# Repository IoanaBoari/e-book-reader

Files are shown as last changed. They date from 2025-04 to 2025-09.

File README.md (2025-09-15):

### OpenBook - Project

## Block Diagram
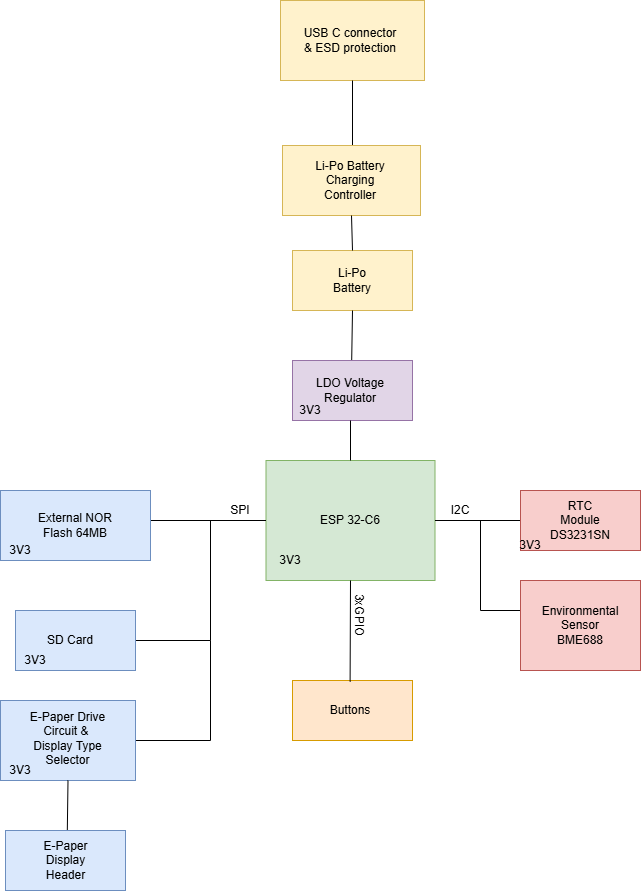
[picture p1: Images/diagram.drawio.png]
Block Diagram

---
## Bill Of Materials (BOM)
| Component | Source | Datasheet |
|---|---|---|
| Button | [Mouser](https://ro.mouser.com/ProductDetail/CK/KMR221GULCLFS?qs=u2NJ%252B70r0goBXaNk7IrU0Q%3D%3D) |[Datasheet](https://www.ckswitches.com/media/1479/kmr2.pdf)|
| Capacitor SUPERCAP | [Mouser](https://ro.mouser.com/ProductDetail/Seiko-Semiconductors/CPH3225A?qs=3etwrb1wR%252BhUOph6lAO7eg%3D%3D) | [Datasheet](https://ro.mouser.com/datasheet/2/360/Seiko_Instruments_MicroBattery_E_20230330_2024Jan_-3561061.pdf)|
| Capacitor 100nF | [Mouser](https://ro.mouser.com/ProductDetail/KEMET/C0402C104K4RAL?qs=pIZUS6sqCWCaMuP2QVR%2Fog%3D%3D) | [Datasheet](https://ro.mouser.com/datasheet/2/447/KEM_C1018_X7R_SnPb_SMD-3316276.pdf)|
| Capacitor 4.7uF | [Mouser](https://ro.mouser.com/ProductDetail/KEMET/C0402C475M9PAC7411?qs=cpo3%2FpBou2jRzZxyxJnMGg%3D%3D) | [Datasheet](https://ro.mouser.com/datasheet/2/447/KEM_C1006_X5R_SMD-3316465.pdf)|
| Capacitor 100uF TANT | [Mouser](https://ro.mouser.com/ProductDetail/KYOCERA-AVX/TAJW107M010RNJ?qs=Wtp%252Bf%2FAeVqIH8v1VxV%252B1Rg%3D%3D) | [Datasheet](https://ro.mouser.com/datasheet/2/40/TAJ-3165264.pdf)|
| Capacitor 4.7uF / 25V | [Mouser](https://ro.mouser.com/ProductDetail/KYOCERA-AVX/12063C475KAZ2A?qs=%252BdQmOuGyFcG3LdbVp5waMw%3D%3D) | [Datasheet](https://ro.mouser.com/datasheet/2/40/X7RDielectric-2943470.pdf)|
| Capacitor 1uF | [Mouser](https://ro.mouser.com/ProductDetail/KEMET/C0402C105K9PACTU?qs=UdQET6xYxVCMExqTDkuPeQ%3D%3D) | [Datasheet](https://ro.mouser.com/datasheet/2/447/KEM_C1006_X5R_SMD-3316465.pdf)|
| Capacitor 10uF | [Mouser](https://ro.mouser.com/ProductDetail/KEMET/C0402C106M9PACTU?qs=x4XeXhDQKnp%252Bz0lMlwMC3A%3D%3D) | [Datasheet](https://ro.mouser.com/datasheet/2/447/KEM_C1006_X5R_SMD-3316465.pdf)|
| CHG_LED | [CPC](https://cpc.farnell.com/kingbright/kpg-1608zgc/led-smd-0603-grn/dp/SC20796) | [Datasheet](https://www.farnell.com/datasheets/2046349.pdf)|
| USBLC6-2SC6Y | [Mouser](https://ro.mouser.com/ProductDetail/STMicroelectronics/USBLC6-2SC6Y?qs=gNDSiZmRJS%2FOgDexvXkdow%3D%3D) | [Datasheet](https://ro.mouser.com/datasheet/2/389/usblc6_2sc6y-1852505.pdf)|
| PGB1010603MR | [Mouser](https://ro.mouser.com/ProductDetail/Littelfuse/PGB1010603MR?qs=gu7KAQ731URLg4GSnNNN7Q%3D%3D) | [Datasheet](https://www.littelfuse.com/assetdocs/pulseguard-esd-suppressors-pgb1-datasheet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)|
| SD0805S020S1R0 | [Mouser](https://ro.mouser.com/ProductDetail/KYOCERA-AVX/SD0805S020S1R0?qs=jCA%252BPfw4LHbpkAoSnwrdjw%3D%3D) | [Datasheet](https://ro.mouser.com/datasheet/2/40/schottky-3165252.pdf)|
| MBR0530 | [Mouser](https://ro.mouser.com/ProductDetail/onsemi/MBR0530T3G?qs=3JMERSakebpEmdUS6GetdQ%3D%3D) | [Datasheet](https://www.onsemi.com/products/discrete-power-modules/schottky-diodes-schottky-rectifiers/mbr0530t3g)|
| Solder Jumper | [Grabcad](https://grabcad.com/library/solder-jumpers-1) | [Datasheet](https://grabcad.com/library/solder-jumpers-1)|
| Capacitor 1uF / 50V | [Mouser](https://ro.mouser.com/ProductDetail/TDK/C1608X7R1H105K080AB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) | [Datasheet](https://product.tdk.com/system/files/dam/doc/product/capacitor/ceramic/mlcc/catalog/mlcc_commercial_general_en.pdf)|
| Capacitor 0.1uF / 50V | [Farnell](https://ro.farnell.com/multicomp-pro/mcmlr50v104kx7r/ceramic-capacitor-0-1uf-50v-x7r/dp/1600875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) | [Datasheet](https://www.farnell.com/datasheets/2873577.pdf?_gl=1*x28a2*_gcl_au*MTYwODAzNzc2OC4xNzQzNDM1MjM4)|
| BD5229G-TR | [Mouser](https://ro.mouser.com/ProductDetail/ROHM-Semiconductor/BD5229G-TR?qs=4kLU8WoGk0vvnhrrYwdszw%3D%3D) | [Datasheet](https://fscdn.rohm.com/en/products/databook/datasheet/ic/power/voltage_detector/bd52xxg-e.pdf)|
| XC6220A331MR-G | [Mouser](https://ro.mouser.com/ProductDetail/Torex-Semiconductor/XC6220A331MR-G?qs=AsjdqWjXhJ8ZSWznL1J0gg%3D%3D) | [Datasheet](https://ro.mouser.com/datasheet/2/760/xc6220-3371556.pdf)|
| FH34SRJ-24S-0.5SH_99_ | [Mouser](https://ro.mouser.com/ProductDetail/Hirose-Connector/FH34SRJ-24S-0.5SH99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) | [Datasheet](https://ro.mouser.com/datasheet/2/185/FH34SRJ_24S_0_5SH_99__CL0580_1255_6_99_2DDrawing_0-1615044.pdf)|
| SAMACSYS_PARTS_USB4110-GF-A | [Mouser](https://ro.mouser.com/ProductDetail/GCT/USB4110-GF-A?qs=KUoIvG%2F9IlYiZvIXQjyJeA%3D%3D) | [Datasheet](https://ro.mouser.com/datasheet/2/837/GCT_USB4110_Product_Drawing___20k_cycles-3455479.pdf)|
| QWIIC_RIGHT_ANGLEA | [Mouser](https://ro.mouser.com/ProductDetail/JST-Commercial/SM04B-SRSS-TBLFSN?qs=cdbOS8ANM9B3FdyA6cNU2A%3D%3D) | [Datasheet](https://ro.mouser.com/datasheet/2/564/eSR_SZ-3476820.pdf)|
| 112A-TAAR-R03_ATTEND | [LCSC](https://www.lcsc.com/product-detail/SD-Card-Connectors_Attend-Technology-112A-TAAR-R03_C6970445.html) | [Datasheet](https://www.lcsc.com/datasheet/lcsc_datasheet_2411220717_Attend-Technology-112A-TAAR-R03_C6970445.pdf)|
| Bobina | [Mouser](https://ro.mouser.com/ProductDetail/Wurth-Elektronik/744043680?qs=PGXP4M47uW6VkZq%252BkzjrHA%3D%3D) | [Datasheet](https://www.we-online.com/components/products/datasheet/744043680.pdf)|
| MCP73831 | [Mouser](https://ro.mouser.com/ProductDetail/Microchip-Technology/MCP73831-2ACI-MC?qs=hH%252BOa0VZEiBneYTVdpuVdg%3D%3D) | [Datasheet](https://ro.mouser.com/datasheet/2/268/MCP73831_Family_Data_Sheet_DS20001984H-3441711.pdf)|
| PFMF.050.1 | [Mouser](https://ro.mouser.com/ProductDetail/Schurter/PFMF.050.2?qs=1auRipcfynCums5v1iucSA%3D%3D) | [Datasheet](https://ro.mouser.com/datasheet/2/358/typ_PFMF-1275918.pdf)|
| DMG2305UX-7 | [Mouser](https://ro.mouser.com/ProductDetail/Diodes-Incorporated/DMG2305UX-7?qs=L1DZKBg7t5F%2FNBHrjfxC%252Bg%3D%3D) | [Datasheet](https://www.diodes.com/assets/Datasheets/DMG2305UX.pdf)|
| SI1308EDL-T1-GE3 | [Mouser](https://ro.mouser.com/ProductDetail/Vishay-Semiconductors/SI1308EDL-T1-GE3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) | [Datasheet](https://www.vishay.com/docs/63399/si1308edl.pdf)|
| Resistor 10K | [DigiKey](https://www.digikey.com/en/products/detail/venkel/CR0402-10W-102JT/12332774) | [Datasheet](https://data.venkel.com/documents/cr-series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.)|
| Resistor 100K | [Venkel](https://venkel.com/part/CR0402-16W-1003FT) | [Datasheet](https://data.venkel.com/documents/cr-series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.)|
| Resistor 5k1 | [Venkel](https://venkel.com/part/CR0402-10W-5101FT) | [Datasheet](https://data.venkel.com/documents/cr-series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.)|
| Resistor 2k | [Venkel](https://www.venkel.com/part/CR0402-16W-2002FT) | [Datasheet](https://data.venkel.com/documents/cr-series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.)|
| Resistor 0.47 | [Mouser](https://ro.mouser.com/ProductDetail/Vishay-Beyschlag/MCT06030C4700FP500?qs=XsZ9OvPb0dt82KlzjdcMjQ%3D%3D) | [Datasheet](https://www.vishay.com/docs/28705/mcx0x0xpro.pdf)|
| BME688 | [Mouser](https://ro.mouser.com/ProductDetail/Bosch-Sensortec/BME688?qs=IS%252B4QmGtzzqQoVDscqwx3A%3D%3D) | [Datasheet](https://ro.mouser.com/datasheet/2/783/bst_bme688_fl000-2307034.pdf)|
| W25Q512JVEIQ | [Mouser](https://ro.mouser.com/ProductDetail/Winbond/W25Q512JVEIQ?qs=l7cgNqFNU1jw6svr3at6tA%3D%3D) | [Datasheet](https://ro.mouser.com/datasheet/2/949/Winbond_W25Q512JV_Datasheet-3240039.pdf)|
| ESP32-C6-WROOM-1-N8 | [Mouser](https://ro.mouser.com/ProductDetail/Espressif-Systems/ESP32-C6-WROOM-1-N8?qs=8Wlm6%252BaMh8ST02Gmwp74cw%3D%3D) | [Datasheet](https://ro.mouser.com/datasheet/2/891/Espressif_ESP32_C6_WROOM_1__Datasheet_V0_1_PRELIMI-3239987.pdf)|
| DS3231SN# | [Mouser](https://ro.mouser.com/ProductDetail/Analog-Devices-Maxim-Integrated/DS3231SN?qs=1eQvB6Dk1vhUlr8%2FOrV0Fw%3D%3D) | [Datasheet](https://ro.mouser.com/datasheet/2/609/DS3231-3421123.pdf)|
| MAX17048G+T10 | [Mouser](https://ro.mouser.com/ProductDetail/Analog-Devices-Maxim-Integrated/MAX17048G%2bT10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) | [Datasheet](https://ro.mouser.com/datasheet/2/609/MAX17048_MAX17049-3469099.pdf)|
| Test Pad | [DigiKey](https://www.digikey.com/en/products/detail/keystone-electronics/5006/255330) | [Datasheet](https://www.keyelco.com/userAssets/file/M65p56.pdf)|

---

# Hardware Functionality

**Power Supply & Energy Management:**
- **USB with ESD:** Provides power and protects data lines.
- **Li-Po Charging Circuit - MCP73831:** Controlled charging for the 1800 mAh battery.
- **Li-Po Battery & LDO Voltage Regulator:** Regulates voltage to 3.3V for all modules.

**Microcontroller & Interfaces:**
- **ESP32-C6:**
    - **SPI:** Connects NOR Flash memory, SD card, and e-paper display.
    - **I2C:** Connects RTC DS3231, BME688 sensor, and expansion modules.
    - **UART:** For debugging and serial communication.
    - **GPIO:** For buttons and test pads.

**Storage & Display Modules:**
- **NOR Flash Memory (SPI)** Fast storage for firmware and data.
- **SD Card (SPI)** Expands storage capacity.
- **E-Paper Display:** Low-power, precise updates, controlled via SPI.

**Additional Modules & Sensors:**
- **RTC DS3231 (I2C):** Real-time clock.
- **BME688 Sensor (I2C):** Measures temperature, humidity, pressure, and air quality.
- **Qwiic/Stemma QT Connector (I2C):** Allows expansion with additional modules.
- **Test Pads & Buttons (GPIO):** Facilitate direct control and diagnostics.

**Power Optimization:**
- **ESP32-C6 Low-Power Mode:** Reduces consumption through dynamic frequency and activity management.
- **Stable LDO:** Ensures a constant 3.3V voltage.
- **SMD Components (e.g., 0402 capacitors):** Minimize consumption through small size and improved efficiency.

---

# ESP32-C6 Pin Mapping

| Nume | GPIO | Usage | Notes |
|---|---|---|---|
| 3V3  | 3V3 | 3.3V Power Supply | Voltage source for ESP32-C6 and logic components. |
| SCK (SPI) | IO6 | SPI Clock | Provides the clock signal for high-speed data transfers. |
| MOSI (SPI) | IO7 | SPI Data Transmission | Sends data to NOR Flash, SD Card, and E-Paper. |
| MISO (SPI) | IO2 | SPI Data Reception | Receives data from SPI devices. |
| FLASH_CS | IO11 | SPI Chip Select for NOR Flash | Selects the NOR Flash memory on the SPI bus. |
| EPD_CS | IO10 | SPI Chip Select for E-Paper | Selects the e-paper display. |
| SDA (I2C) | IO21 | I2C Data Line | Connects RTC DS3231, BME688 sensor, and Qwiic/Stemma QT connector. |
| SCL (I2C) | IO22 | I2C Clock Line | Synchronizes I2C communication. |
| TX (UART) | TXD0/GPIO16 | UART Data Transmission | Used for debugging and serial communication. |
| RX (UART) | RXD0/GPIO17 | UART Data Reception | Used for debugging and serial communication. |
| Buton Reset | EN | ESP32-C6 Reset | Pin dedicat pentru resetul sistemului. |
| Buton Boot | IO9 | Bootloader Entry | Dedicated pin to enter boot mode. |
| Buton Change | IO15 | Operation Mode Switch | Allows switching between different operating modes. |
| EPD DC | IO5 | Data/Command for E-Paper | Distinguishes between command and data signals for the display. |
| EPD RST | IO23 | E-Paper Reset | Resets the e-paper display when needed. |
| EPD BUSY | IO3 | E-Paper Busy Indicator | Signal indicating if the display is currently busy. |
| INT_RTC | IO0 | RTC Interrupt Signal (DS3231) | Triggers the microcontroller. |
| 32KHZ | IO1 | 32 kHz Clock Signal | Oscillation line for DS3231 or other modules (not directly connected to ESP). |
| SS_SD| IO4 | SPI Chip Select for SD Card | Selects the SD card on the SPI bus. |
| USB_D- | IO12 | USB Differential Line (minus) | Connection to the USB port. |
| USB_D+ | IO13 | USB Differential Line (plus) | Connection to the USB port. |
| RTC_RST | IO18 | External RTC Reset/Signal | Used to reset the real-time clock. |
| I2C_PW | IO19 | I2C Power/Enable Line | Turns I2C sensors on/off to save energy. |
| EPD_3V3_C | IO20 | 3.3V Power Line for E-Paper | Provides 3.3V specifically for the e-paper display, separate from main power, to ensure signal stability. |

---
## Motivation

- **SPI** (SCK, MOSI, MISO, CS lines) provides fast transfer for external memory (Flash), SD card, and e-paper display.
- **I2C** (SDA, SCL) connects sensors (RTC, BME688) and the Qwiic connector, allowing bus sharing with low power consumption.
- **UART** (TX, RX) is used for debugging.
- **Additional GPIOs** (buttons, test pads) facilitate manual control and diagnostics.

---

## Implementation Steps

- **Schematic:** Created the schematic according to the project requirements.
- **PCB Redesign:** Redesigned the PCB and placed components on the board based on the reference model.
- **Autorouting:** Performed autorouting on both top and bottom layers, using a 0.15 mm trace width for signal lines.
- **Power Net Class:** Grouped power traces into a net class, highlighted them, and manually adjusted to 0.3 mm to ensure robust power delivery.
- **Ground Planes and Via Stitching:** Added ground planes on top and bottom layers and applied via stitching near the ESP module for optimal inter-layer connectivity.
- **3D Models:** Downloaded component 3D models from [ComponentSearchEngine](https://componentsearchengine.com/), imported them into Fusion 360, and placed them on the PCB.
- **Enclosure Integration:** Inserted the PCB into the enclosure and modified it to properly fit the buttons and connectors.
- **3D Models for Battery and Display:** Created 3D models for the battery and display, connecting wires to the corresponding test pads and ensuring correct placement inside the enclosure.
- **Export:** Finally, generated Gerber files, Pick and Place (CPL), and BOM, preparing them for upload and production.

---

## Issues Encountered and Error Acceptance Decisions

- **3D Model for Button:**  
  Could not find a 3D model for the button that perfectly matched the project requirements, so I modified an existing model to fit the design.

- **SMD-Hole Board Outline Clearance Errors at USB Connector:**  
  Encountered two SMD-Hole Board Outline Clearance errors at the USB connector. These errors were accepted according to the provided guidelines.
---

## Conclusion
 I resolved the reported issues by adjusting the PCB thickness and adding 3D models for the solder jumper and test pads.
 For the test pads, I implemented a custom model.

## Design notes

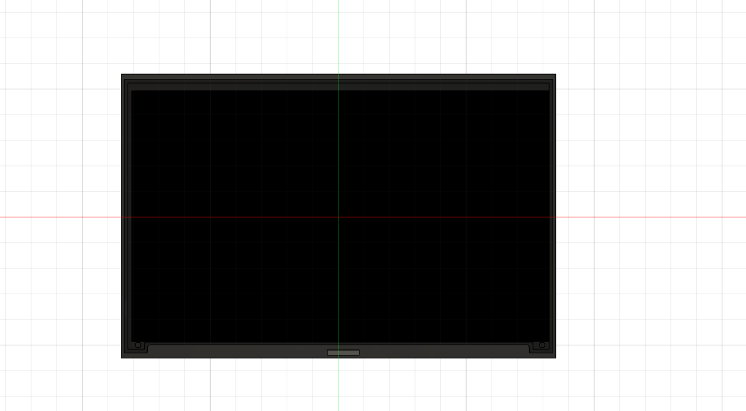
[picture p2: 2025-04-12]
Images/Display1.png

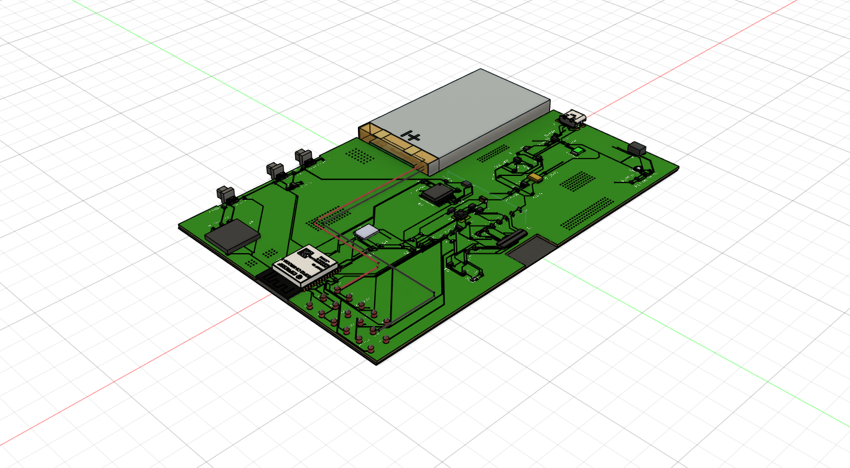
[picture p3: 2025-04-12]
Images/Dispozitiv6.png

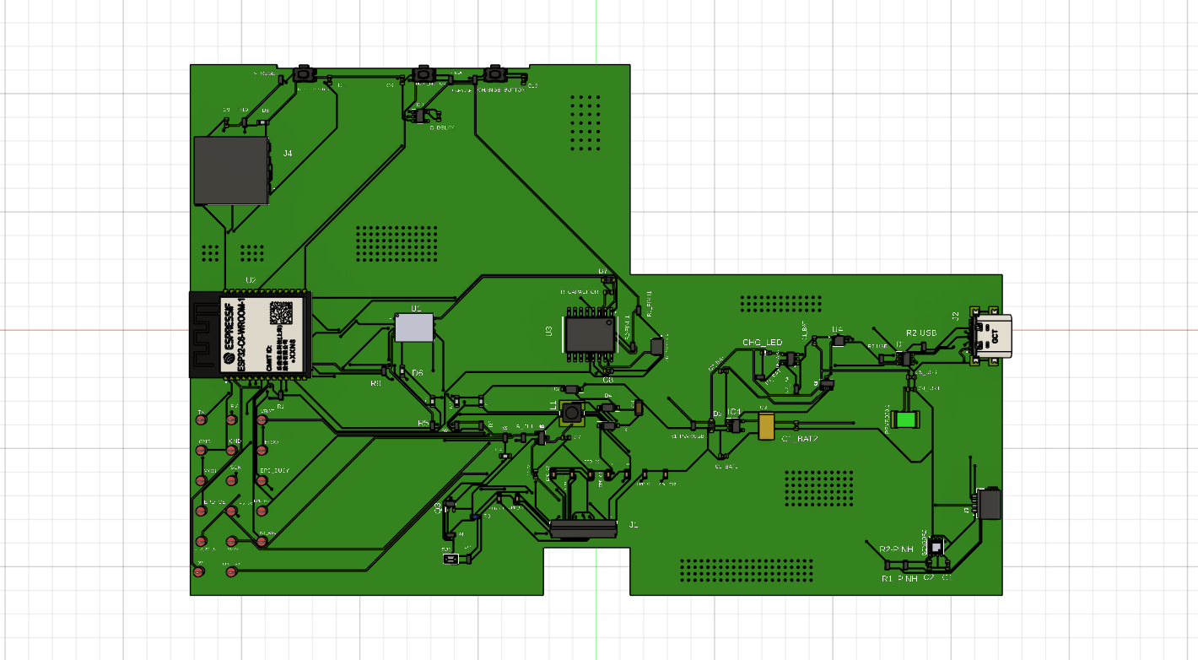
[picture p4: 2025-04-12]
Images/Board1.png

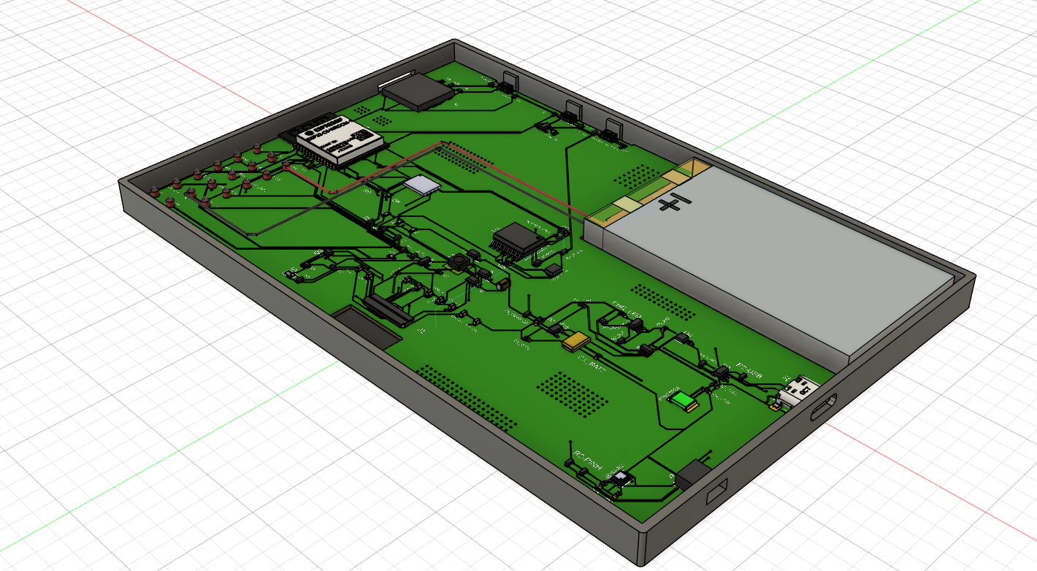
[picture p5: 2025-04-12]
Images/Dispozitiv3.png

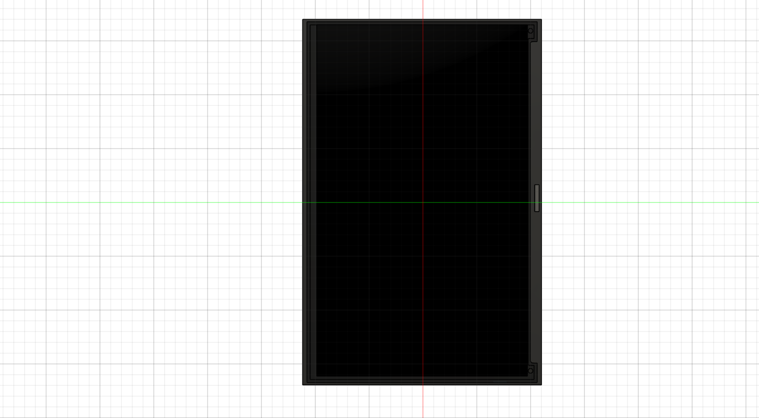
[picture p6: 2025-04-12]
Images/Display2.png

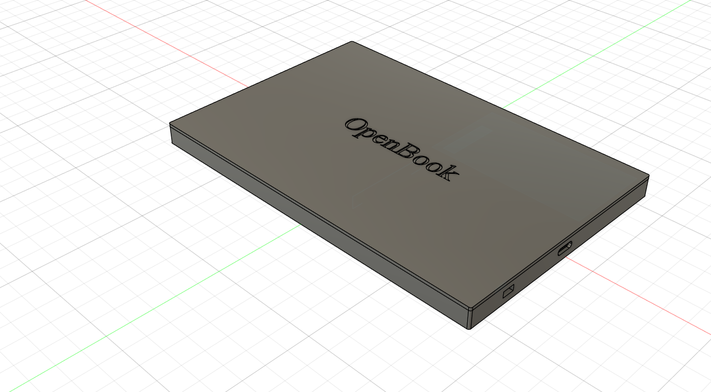
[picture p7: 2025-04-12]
Images/Dispozitiv1.png

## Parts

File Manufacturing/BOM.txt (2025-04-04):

BOOT_BUTTON	49.00	108.91	180.00	BUTTON_CUSYOMV1	MYBUTTON
C1	158.75	6.35	90.00	100nF	ESP32_WROVER_EAGLE-LTSPICE_C0402
C10	69.85	107.95	90.00	100nF	ESP32_WROVER_EAGLE-LTSPICE_C0402
C10_SUPERCAP	97.79	52.07	270.00	CPH3225A	CAPCP3225X100N
C1_BAT	130.81	53.34	90.00	4.7uF	ESP32_WROVER_EAGLE-LTSPICE_C0402
C1_BAT1	111.76	29.21	0.00	4.7uF	ESP32_WROVER_EAGLE-LTSPICE_C0402
C1_BAT2	127.00	35.56	270.00	4.7uF	EAGLE-LTSPICE_C0402
C2	154.94	6.35	90.00	100nF	ESP32_WROVER_EAGLE-LTSPICE_C0402
C2_BAT	111.76	46.99	0.00	4.7uF	ESP32_WROVER_EAGLE-LTSPICE_C0402
C3	120.65	35.56	270.00	100uF TANT	RCL_CT3528
C4	93.98	39.37	90.00	4.7uF/25V	ESP32_WROVER_EAGLE-LTSPICE_C0402
C4_USB	151.13	43.18	0.00	100nF	ESP32_WROVER_EAGLE-LTSPICE_C0402
C5	29.21	107.95	90.00	1uF	ESP32_WROVER_EAGLE-LTSPICE_C0402
C5_USB	151.13	45.72	0.00	4.7uF	ESP32_WROVER_EAGLE-LTSPICE_C0402
C6	44.45	107.95	90.00	100nF	ESP32_WROVER_EAGLE-LTSPICE_C0402
C7	78.74	33.02	0.00	10uF	ESP32_WROVER_EAGLE-LTSPICE_C0402
C8	87.63	46.99	0.00	100nF	ESP32_WROVER_EAGLE-LTSPICE_C0402
C9	7.62	99.06	90.00	100nF	ESP32_WROVER_EAGLE-LTSPICE_C0402
CHANGE_BUTTON	64.00	108.91	180.00	BUTTON_CUSYOMV1	MYBUTTON
CHG_LED	120.65	50.80	90.00		ADAFRUIT_CHIP-LED0603
C_DELAY	52.07	100.33	90.00	100nF	ESP32_WROVER_EAGLE-LTSPICE_C0402
D1	149.86	49.53	0.00	USBLC6-2SC6Y	SOT95P280X145-6N
D10	55.88	40.64	90.00	PGB1010603MR	DIOC1608X36N
D11	60.96	40.64	90.00	PGB1010603MR	DIOC1608X36N
D12	66.04	29.21	0.00	PGB1010603MR	DIOC1608X36N
D2	109.22	35.56	90.00	ESP32_WROVER_AVX---SD0805S020S1R0_AVX_SD0805S020S1R0_0_0AVX_SD0805S020S1R0_0_0	ESP32_WROVER_AVX---SD0805S020S1R0_AVX_SD0805S020S1R0_0
D3	80.01	43.18	180.00	MBR0530	SOD3716X135N
D4	87.63	39.37	180.00	MBR0530	SOD3716X135N
D5	87.63	35.56	0.00	MBR0530	SOD3716X135N
D6	44.45	46.99	90.00	PGB1010603MR	DIOC1608X36N
D7	87.63	66.04	0.00	ESP32_WROVER_AVX---SD0805S020S1R0_AVX_SD0805S020S1R0_0_0AVX_SD0805S020S1R0_0_0	ESP32_WROVER_AVX---SD0805S020S1R0_AVX_SD0805S020S1R0_0
D8	15.24	99.06	0.00	PGB1010603MR	DIOC1608X36N
D9	50.80	40.64	90.00	PGB1010603MR	DIOC1608X36N
EPD_C1	64.77	20.32	90.00	1uF/50V	ESP32_WROVER_EAGLE-LTSPICE_C0402
EPD_C10	91.44	25.40	90.00	1uF/50V	ESP32_WROVER_EAGLE-LTSPICE_C0402
EPD_C11	95.25	25.40	90.00	1uF/50V	ESP32_WROVER_EAGLE-LTSPICE_C0402
EPD_C12	99.58	25.40	90.00	1uF/50V	ESP32_WROVER_EAGLE-LTSPICE_C0402
EPD_C2	68.58	20.32	90.00	1uF/50V	ESP32_WROVER_EAGLE-LTSPICE_C0402
EPD_C5	72.39	25.40	90.00	0.1uF/50V	ESP32_WROVER_EAGLE-LTSPICE_C0402
EPD_C6	76.20	25.40	90.00	1uF/50V	ESP32_WROVER_EAGLE-LTSPICE_C0402
EPD_C7	80.01	25.40	90.00	1uF/50V	ESP32_WROVER_EAGLE-LTSPICE_C0402
EPD_C8	83.82	25.40	90.00	1uF/50V	ESP32_WROVER_EAGLE-LTSPICE_C0402
EPD_C9	87.63	25.40	90.00	1uF/50V	ESP32_WROVER_EAGLE-LTSPICE_C0402
IC1	48.26	100.33	0.00	BD5229G-TR	SOT95P280X125-5N
IC4	114.30	35.56	0.00	XC6220A331MR-G	SOT95P280X120-5N
J1	82.42	14.20	0.00	FH34SRJ-24S-0.5SH_99_	FH34SRJ24S05SH99
J2	166.09	54.30	90.00	SAMACSYS_PARTS_USB4110-GF-A	SAMACSYS_PARTS_USB4110GFA
J3	166.35	19.30	90.00	QWIIC_RIGHT_ANGLE	JST04_1MM_RA
J4	9.09	88.88	270.00	112A-TAAR-R03_ATTEND	112ATAARR03ATTEND
L1	80.01	38.10	270.00	68uH	IND_4828-WE-TPC_WRE
MCP73831	125.73	49.53	90.00	MCP73831	ESP32_WROVER_SPARKFUN-IC-POWER_SOT23-5
PFMF.050.1	149.86	36.83	0.00	ESP32C6_VARISTORCN1812	ESP32C6_VARISTOR_CT/CN1812
Q1	133.35	44.50	0.00	20V/4.2A/52mΩ/1.4W	ESP32_WROVER_SPARKFUN-DISCRETESEMI_SOT23-3
Q2	73.71	33.02	270.00	20V/4.2A/52mΩ/1.4W	ESP32_WROVER_SPARKFUN-DISCRETESEMI_SOT23-3
Q3	54.61	19.05	90.00	SI1308EDL-T1-GE3	SOT65P210X110-3N
R1	19.05	41.91	90.00	10K	ESP32_WROVER_EAGLE-LTSPICE_R0402
R10	11.43	99.06	90.00	10K	ESP32_WROVER_EAGLE-LTSPICE_R0402
R1_BAT	119.38	45.72	0.00	200	ESP32_WROVER_EAGLE-LTSPICE_R0402
R1_PINH	149.86	6.35	90.00	10K	ESP32_WROVER_EAGLE-LTSPICE_R0402
R1_PINH1	93.98	59.69	90.00	10K	ESP32_WROVER_EAGLE-LTSPICE_R0402
R1_PWRUSB	105.41	35.56	90.00	100K	ESP32_WROVER_EAGLE-LTSPICE_R0402
R2	58.42	7.62	90.00	2.2	ESP32_WROVER_EAGLE-LTSPICE_R0402
R2-PINH	146.05	6.35	90.00	10K	ESP32_WROVER_EAGLE-LTSPICE_R0402
R2-PINH1	92.71	52.07	90.00	10K	ESP32_WROVER_EAGLE-LTSPICE_R0402
R2-USB	153.67	52.07	90.00	5K1	ESP32_WROVER_EAGLE-LTSPICE_R0402
R2-USB1	144.78	49.53	90.00	5K1	ESP32_WROVER_EAGLE-LTSPICE_R0402
R2_BAT	127.00	43.18	90.00	2K	ESP32_WROVER_EAGLE-LTSPICE_R0402
R3	59.69	16.51	0.00	0.47	ESP32_WROVER_EAGLE-LTSPICE_R0402
R4	54.61	12.70	0.00	10K	ESP32_WROVER_EAGLE-LTSPICE_R0402
R5	50.80	35.56	90.00	10K	ESP32_WROVER_EAGLE-LTSPICE_R0402
R6	55.88	35.56	90.00	10K	ESP32_WROVER_EAGLE-LTSPICE_R0402
R7	60.96	35.56	90.00	10K	ESP32_WROVER_EAGLE-LTSPICE_R0402
R8	66.04	33.02	90.00	10K	ESP32_WROVER_EAGLE-LTSPICE_R0402
R9	40.64	46.99	90.00	10K	ESP32_WROVER_EAGLE-LTSPICE_R0402
RESET_BUTTON	24.00	108.91	180.00	BUTTON_CUSYOMV1	MYBUTTON
R_BOOT	54.61	107.95	90.00	10K	ESP32_WROVER_EAGLE-LTSPICE_R0402
R_CAPACITOR	87.63	63.50	180.00	15	ESP32_WROVER_EAGLE-LTSPICE_R0402
R_CHANGE	59.69	107.95	90.00	10K	ESP32_WROVER_EAGLE-LTSPICE_R0402
R_CL1	69.85	33.02	90.00	10K	ESP32_WROVER_EAGLE-LTSPICE_R0402
R_RESET	19.05	107.95	90.00	10K	ESP32_WROVER_EAGLE-LTSPICE_R0402
SENSOR2	156.22	10.16	90.00	BME688	ESP32_WROVER_BME680_PSON80P300X300X100-8N
SJ1	54.61	7.62	0.00		SJ
TP1	2.54	36.83	0.00	TPTP20R	TP20R
TP10	2.54	17.78	0.00	TPTP20R	TP20R
TP11	8.89	17.78	0.00	TPTP20R	TP20R
TP12	15.24	17.78	0.00	TPTP20R	TP20R
TP13	2.54	11.43	0.00	TPTP20R	TP20R
TP14	8.89	11.43	0.00	TPTP20R	TP20R
TP15	15.24	11.43	0.00	TPTP20R	TP20R
TP16	2.02	5.08	0.00	TPTP20R	TP20R
TP17	8.89	5.08	0.00	TPTP20R	TP20R
TP2	8.89	36.83	0.00	TPTP20R	TP20R
TP3	15.24	36.83	0.00	TPTP20R	TP20R
TP4	2.54	30.48	0.00	TPTP20R	TP20R
TP5	8.89	30.48	0.00	TPTP20R	TP20R
TP6	15.24	30.48	0.00	TPTP20R	TP20R
TP7	2.54	24.13	0.00	TPTP20R	TP20R
TP8	8.89	24.13	0.00	TPTP20R	TP20R
TP9	15.24	24.13	0.00	TPTP20R	TP20R
U1	46.99	56.09	0.00	W25Q512JVEIQ	SON127P600X800X80-9N
U2	15.70	54.61	90.00	ESP32-C6-WROOM-1-N8	XCVR_ESP32-C6-WROOM-1-N8
U3	83.82	54.61	270.00	DS3231SN#	SOIC127P1032X265-16N
U4	135.89	53.34	0.00	MAX17048G+T10	SON50P200X200X80-9N

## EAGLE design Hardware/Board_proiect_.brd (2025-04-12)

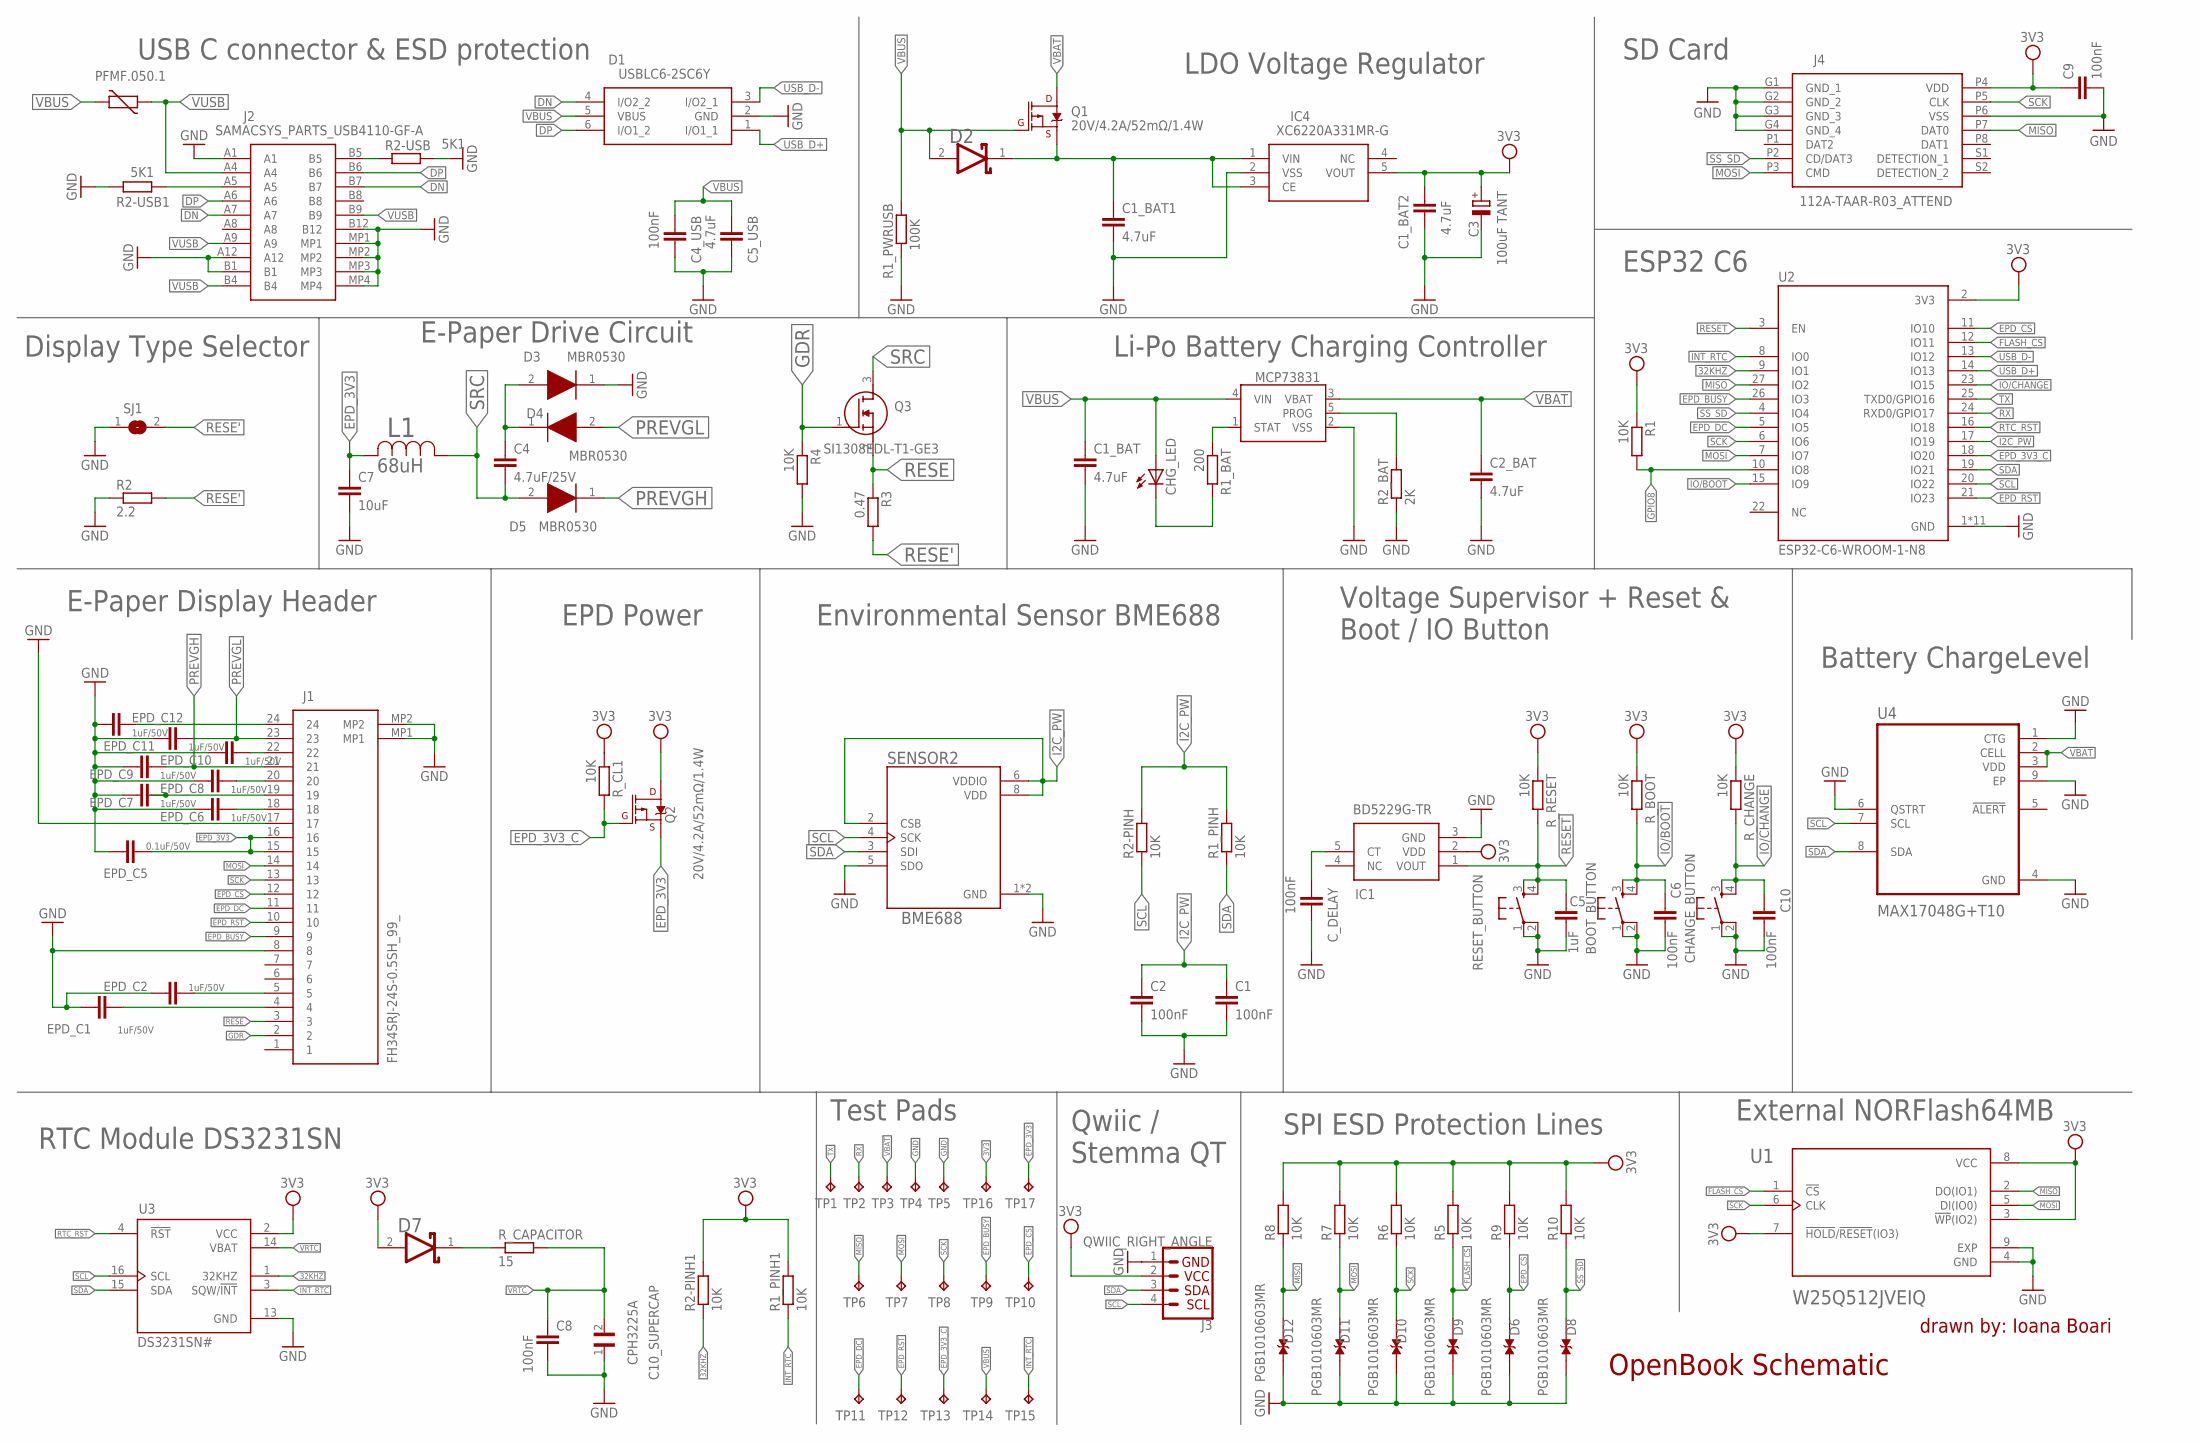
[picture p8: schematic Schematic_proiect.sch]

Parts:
BOOT_BUTTON: BUTTON_CUSYOMV1; MYBUTTON
C1, C2, C4_USB, C6, C8, C9, C10: 100nF; ESP32_WROVER_EAGLE-LTSPICE_C0402
C1_BAT, C1_BAT1, C2_BAT, C5_USB: 4.7uF; ESP32_WROVER_EAGLE-LTSPICE_C0402
C1_BAT2: 4.7uF; EAGLE-LTSPICE_C0402
C3: 100uF TANT; RCL_CT3528
C4: 4.7uF/25V; ESP32_WROVER_EAGLE-LTSPICE_C0402
C5: 1uF; ESP32_WROVER_EAGLE-LTSPICE_C0402
C7: 10uF; ESP32_WROVER_EAGLE-LTSPICE_C0402
C10_SUPERCAP: CPH3225A; CAPCP3225X100N
CHANGE_BUTTON: BUTTON_CUSYOMV1; MYBUTTON
CHG_LED: ADAFRUIT_LEDCHIP-LED0603; ADAFRUIT_CHIP-LED0603
C_DELAY: 100nF; ESP32_WROVER_EAGLE-LTSPICE_C0402
D1: USBLC6-2SC6Y; SOT95P280X145-6N
D2, D7: ESP32_WROVER_AVX---SD0805S020S1R0_AVX_SD0805S020S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; ESP32_WROVER_AVX---SD0805S020S1R0_AVX_SD0805S020S1R0_0
D3, D4, D5: MBR0530; SOD3716X135N
D6, D8, D9, D10, D11, D12: PGB1010603MR; DIOC1608X36N
EPD_C1, EPD_C2, EPD_C6, EPD_C7, EPD_C8, EPD_C9, EPD_C10, EPD_C11, EPD_C12: 1uF/50V; ESP32_WROVER_EAGLE-LTSPICE_C0402
EPD_C5: 0.1uF/50V; ESP32_WROVER_EAGLE-LTSPICE_C0402
IC1: BD5229G-TR; SOT95P280X125-5N
IC4: XC6220A331MR-G; SOT95P280X120-5N
J1: FH34SRJ-24S-0.5SH_99_; FH34SRJ24S05SH99
J2: SAMACSYS_PARTS_USB4110-GF-A; SAMACSYS_PARTS_USB4110GFA
J3: QWIIC_RIGHT_ANGLE; JST04_1MM_RA
J4: 112A-TAAR-R03_ATTEND; 112ATAARR03ATTEND
L1: 68uH; IND_4828-WE-TPC_WRE
MCP73831: MCP73831; ESP32_WROVER_SPARKFUN-IC-POWER_SOT23-5
PFMF.050.1: ESP32C6_VARISTORCN1812; ESP32C6_VARISTOR_CT/CN1812
Q1, Q2: 20V/4.2A/52mΩ/1.4W; ESP32_WROVER_SPARKFUN-DISCRETESEMI_SOT23-3
Q3: SI1308EDL-T1-GE3; SOT65P210X110-3N
R1, R1_PINH, R1_PINH1, R2-PINH, R2-PINH1, R4, R5, R6, R7, R8, R9, R10: 10K; ESP32_WROVER_EAGLE-LTSPICE_R0402
R1_BAT: 200; ESP32_WROVER_EAGLE-LTSPICE_R0402
R1_PWRUSB: 100K; ESP32_WROVER_EAGLE-LTSPICE_R0402
R2: 2.2; ESP32_WROVER_EAGLE-LTSPICE_R0402
R2-USB, R2-USB1: 5K1; ESP32_WROVER_EAGLE-LTSPICE_R0402
R2_BAT: 2K; ESP32_WROVER_EAGLE-LTSPICE_R0402
R3: 0.47; ESP32_WROVER_EAGLE-LTSPICE_R0402
RESET_BUTTON: BUTTON_CUSYOMV1; MYBUTTON
R_BOOT: 10K; ESP32_WROVER_EAGLE-LTSPICE_R0402
R_CAPACITOR: 15; ESP32_WROVER_EAGLE-LTSPICE_R0402
R_CHANGE: 10K; ESP32_WROVER_EAGLE-LTSPICE_R0402
R_CL1: 10K; ESP32_WROVER_EAGLE-LTSPICE_R0402
R_RESET: 10K; ESP32_WROVER_EAGLE-LTSPICE_R0402
SENSOR2: BME688; ESP32_WROVER_BME680_PSON80P300X300X100-8N
SJ1: SJ
TP1, TP2, TP3, TP4, TP5, TP6, TP7, TP8, TP9, TP10, TP11, TP12, TP13, TP14, TP15, TP16, TP17: TPTP20R; TP20R
U1: W25Q512JVEIQ; SON127P600X800X80-9N
U2: ESP32-C6-WROOM-1-N8; XCVR_ESP32-C6-WROOM-1-N8
U3: DS3231SN#; SOIC127P1032X265-16N
U4: MAX17048G+T10; SON50P200X200X80-9N

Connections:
3V3: C1_BAT2.1, C3.+, C9.1, D7.2 (ANODE), IC1.2 (VDD), IC4.5 (VOUT), J3.2, J4.P4 (VDD), Q2.3 (D), R1.1, R1_PINH1.2, R2-PINH1.2, R5.2, R6.2, R7.2, R8.2, R9.2, R10.2, R_BOOT.1, R_CHANGE.1, R_CL1.1, R_RESET.1, TP16.TP, U1.3 (!WP!(IO2)), U1.7 (!HOLD!/!RESET!(IO3)), U1.8 (VCC), U2.2 (3V3), U3.2 (VCC)
32KHZ: R2-PINH1.1, U2.9 (IO1), U3.1 (32KHZ)
DN: D1.4 (I/O2_2), J2.A7, J2.B7
DP: D1.6 (I/O1_2), J2.A6, J2.B6
EPD_3V3: C7.1, EPD_C5.1, J1.15, J1.16, L1.2, Q2.2 (S), TP17.TP
EPD_3V3_C: Q2.1 (G), R_CL1.2, TP13.TP, U2.18 (IO20)
EPD_BUSY: J1.9, TP9.TP, U2.26 (IO3)
EPD_CS: D6.1, J1.12, R9.1, TP10.TP, U2.11 (IO10)
EPD_DC: J1.11, TP11.TP, U2.5 (IO5)
EPD_RST: J1.10, TP12.TP, U2.21 (IO23)
FLASH_CS: D9.1, R5.1, U1.1 (!CS), U2.12 (IO11)
GDR: J1.2, Q3.1 (G), R4.1
GND: BOOT_BUTTON.1, BOOT_BUTTON.2, C1.2, C1_BAT.2, C1_BAT1.2, C1_BAT2.2, C2.2, C2_BAT.2, C3.-, C4_USB.2, C5.2, C5_USB.2, C6.2, C7.2, C8.2, C9.2, C10.2, C10_SUPERCAP.1, CHANGE_BUTTON.1, CHANGE_BUTTON.2, C_DELAY.2, D1.2 (GND), D3.1 (K), D6.2, D8.2, D9.2, D10.2, D11.2, D12.2, EPD_C1.2, EPD_C2.2, EPD_C5.2, EPD_C6.2, EPD_C7.2, EPD_C8.2, EPD_C9.2, EPD_C10.2, EPD_C11.2, EPD_C12.2, IC1.3 (GND), IC4.2 (VSS), J1.8, J1.17, J1.MP1, J1.MP2, J2.A1, J2.A12, J2.B1, J2.B12, J2.MP1, J2.MP2, J2.MP3, J2.MP4, J3.1, J4.G1 (GND_1), J4.G2 (GND_2), J4.G3 (GND_3), J4.G4 (GND_4), J4.P6 (VSS), MCP73831.2 (VSS), R1_PWRUSB.1, R2.1, R2-USB.2, R2-USB1.1, R2_BAT.1, R4.2, RESET_BUTTON.1, RESET_BUTTON.2, SENSOR2.1 (GND), SENSOR2.5 (SDO), SENSOR2.7 (GND), SJ1.1, TP4.TP, TP5.TP, U1.4 (GND), U1.9 (EXP), U2.1 (GND), U2.28 (GND), U2.29_1 (GND), U2.29_2 (GND), U2.29_3 (GND), U2.29_4 (GND), U2.29_5 (GND), U2.29_6 (GND), U2.29_7 (GND), U2.29_8 (GND), U2.29_9 (GND), U3.13 (GND), U4.1 (CTG), U4.4 (GND), U4.6 (QSTRT), U4.9 (EP)
GPIO8: R1.2, U2.10 (IO8)
I2C_PW: C1.1, C2.1, R1_PINH.2, R2-PINH.2, SENSOR2.2 (CSB), SENSOR2.6 (VDDIO), SENSOR2.8 (VDD), U2.17 (IO19)
INT_RTC: R1_PINH1.1, TP15.TP, U2.8 (IO0), U3.3 (SQW/!INT)
IO/BOOT: BOOT_BUTTON.3, BOOT_BUTTON.4, C6.1, R_BOOT.2, U2.15 (IO9)
IO/CHANGE: C10.1, CHANGE_BUTTON.3, CHANGE_BUTTON.4, R_CHANGE.2, U2.23 (IO15)
MISO: D12.1, J4.P7 (DAT0), R8.1, TP6.TP, U1.2 (DO(IO1)), U2.27 (IO2)
MOSI: D11.1, J1.14, J4.P3 (CMD), R7.1, TP7.TP, U1.5 (DI(IO0)), U2.7 (IO7)
unnamed: D7.1 (CATHODE), R_CAPACITOR.1
unnamed: EPD_C1.1, J1.4
unnamed: EPD_C2.1, J1.5
unnamed: EPD_C6.1, J1.18
unnamed: EPD_C7.1, J1.19
unnamed: EPD_C8.1, J1.20
unnamed: C_DELAY.1, IC1.5 (CT)
unnamed: EPD_C10.1, J1.22
unnamed: C4.1, D3.2 (A), D4.1 (K)
unnamed: EPD_C12.1, J1.24
unnamed: MCP73831.1 (STAT), R1_BAT.1
unnamed: CHG_LED.C, R1_BAT.2
unnamed: MCP73831.5 (PROG), R2_BAT.2
unnamed: J2.A5, R2-USB1.2
unnamed: J2.B5, R2-USB.1
unnamed: C1_BAT1.1, D2.1 (CATHODE), IC4.1 (VIN), IC4.3 (CE), Q1.2 (S)
PREVGH: D5.1 (K), EPD_C9.1, J1.21
PREVGL: D4.2 (A), EPD_C11.1, J1.23
RESE: J1.3, Q3.2 (S), R3.1
RESE': R2.2, R3.2, SJ1.2
RESET: C5.1, IC1.1 (VOUT), RESET_BUTTON.3, RESET_BUTTON.4, R_RESET.2, U2.3 (EN)
RTC_RST: U2.16 (IO18), U3.4 (!RST)
RX: TP2.TP, U2.24 (RXD0/GPIO17)
SCK: D10.1, J1.13, J4.P5 (CLK), R6.1, TP8.TP, U1.6 (CLK), U2.6 (IO6)
SCL: J3.4, R2-PINH.1, SENSOR2.4 (SCK), U2.20 (IO22), U3.16 (SCL), U4.7 (SCL)
SDA: J3.3, R1_PINH.1, SENSOR2.3 (SDI), U2.19 (IO21), U3.15 (SDA), U4.8 (SDA)
SRC: C4.2, D5.2 (A), L1.1, Q3.3 (D)
SS_SD: D8.1, J4.P2 (CD/DAT3), R10.1, U2.4 (IO4)
TX: TP1.TP, U2.25 (TXD0/GPIO16)
USB_D+: D1.1 (I/O1_1), U2.14 (IO13)
USB_D-: D1.3 (I/O2_1), U2.13 (IO12)
VBAT: C2_BAT.1, MCP73831.3 (VBAT), Q1.3 (D), TP3.TP, U4.2 (CELL), U4.3 (VDD)
VBUS: C1_BAT.1, C4_USB.1, C5_USB.1, CHG_LED.A, D1.5 (VBUS), D2.2 (ANODE), MCP73831.4 (VIN), PFMF.050.1.2, Q1.1 (G), R1_PWRUSB.2, TP14.TP
VRTC: C8.1, C10_SUPERCAP.2, R_CAPACITOR.2, U3.14 (VBAT)
VUSB: J2.A4, J2.A9, J2.B4, J2.B9, PFMF.050.1.1

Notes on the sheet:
SD Card
ESP32 C6
Battery ChargeLevel
External NORFlash64MB
SPI ESD Protection Lines
Qwiic / Stemma QT
Test Pads
RTC Module DS3231SN
E-Paper Display Header
EPD Power
Environmental Sensor BME688
Voltage Supervisor + Reset & Boot / IO Button
Display Type Selector
E-Paper Drive Circuit
Li-Po Battery Charging Controller
USB C connector & ESD protection
LDO Voltage Regulator
OpenBook Schematic
drawn by: Ioana Boari

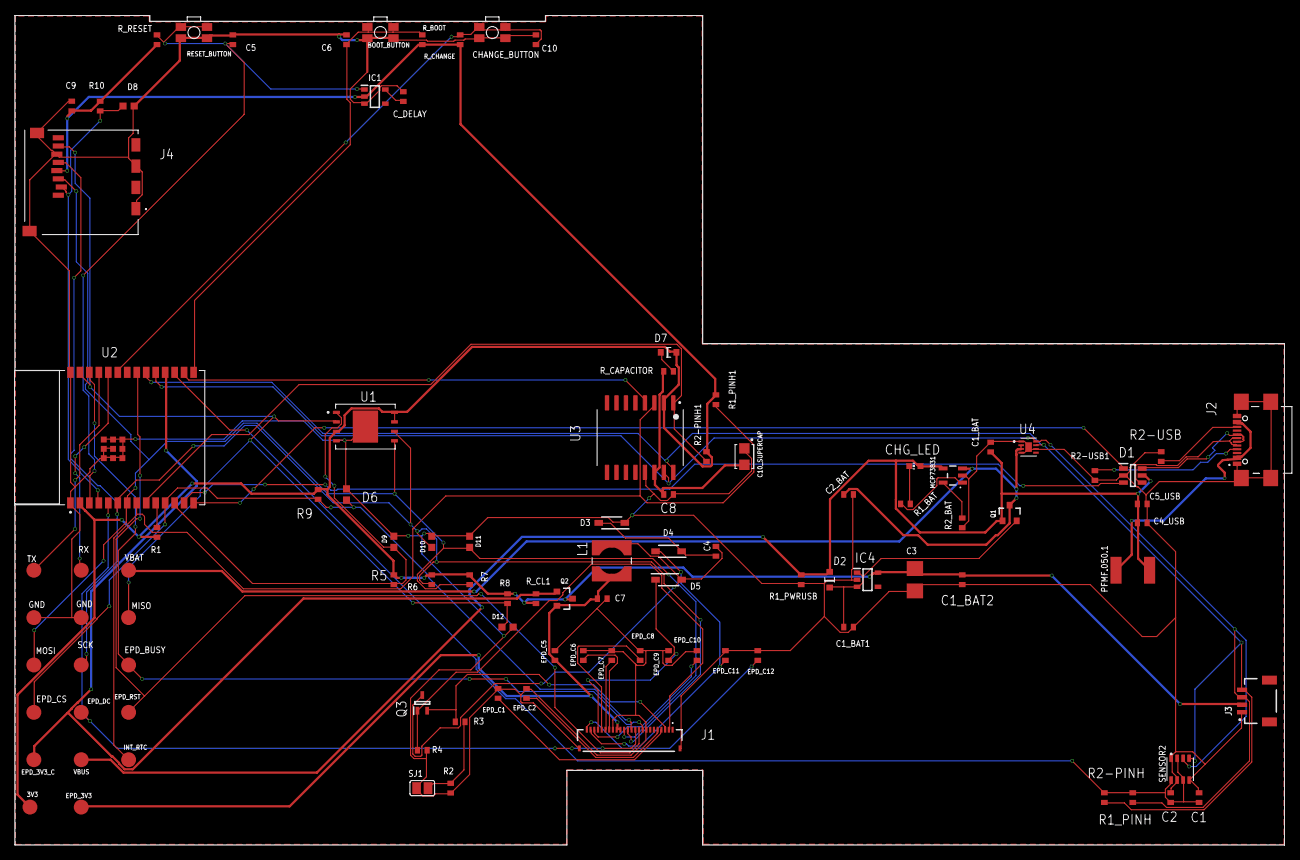
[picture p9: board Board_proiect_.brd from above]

Board: 2 copper layers, 170.2 x 111.2 mm, 103 parts (0 on the bottom side), 55 nets.

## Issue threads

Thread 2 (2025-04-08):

3d Models

todi-mih, 2025-04-08:
Missing 3d models for test pad and solder jumpers.

Closed 2025-04-12.

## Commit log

2025-04-12 Updated hardware to solve issues
    [Board_proiect_.brd, Schematic_proiect.sch]
2025-04-12 Updated Manufacturing files after solving issues
    [PickandPlace.csv]

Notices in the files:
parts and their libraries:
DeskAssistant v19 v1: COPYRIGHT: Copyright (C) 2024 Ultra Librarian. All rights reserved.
